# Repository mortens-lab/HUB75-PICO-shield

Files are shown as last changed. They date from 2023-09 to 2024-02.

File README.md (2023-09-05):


# HUB75-PICO-shield
HUB75 matrix display shield controlled by a Raspberry Pi Pico W

KiCad 7.0 files for shield

IMAGE ALT TEXT (http://www.youtube.com/watch?v=hoFy992Y98c "Video Title")

Link to youtube video : (https://youtu.be/hoFy992Y98c)

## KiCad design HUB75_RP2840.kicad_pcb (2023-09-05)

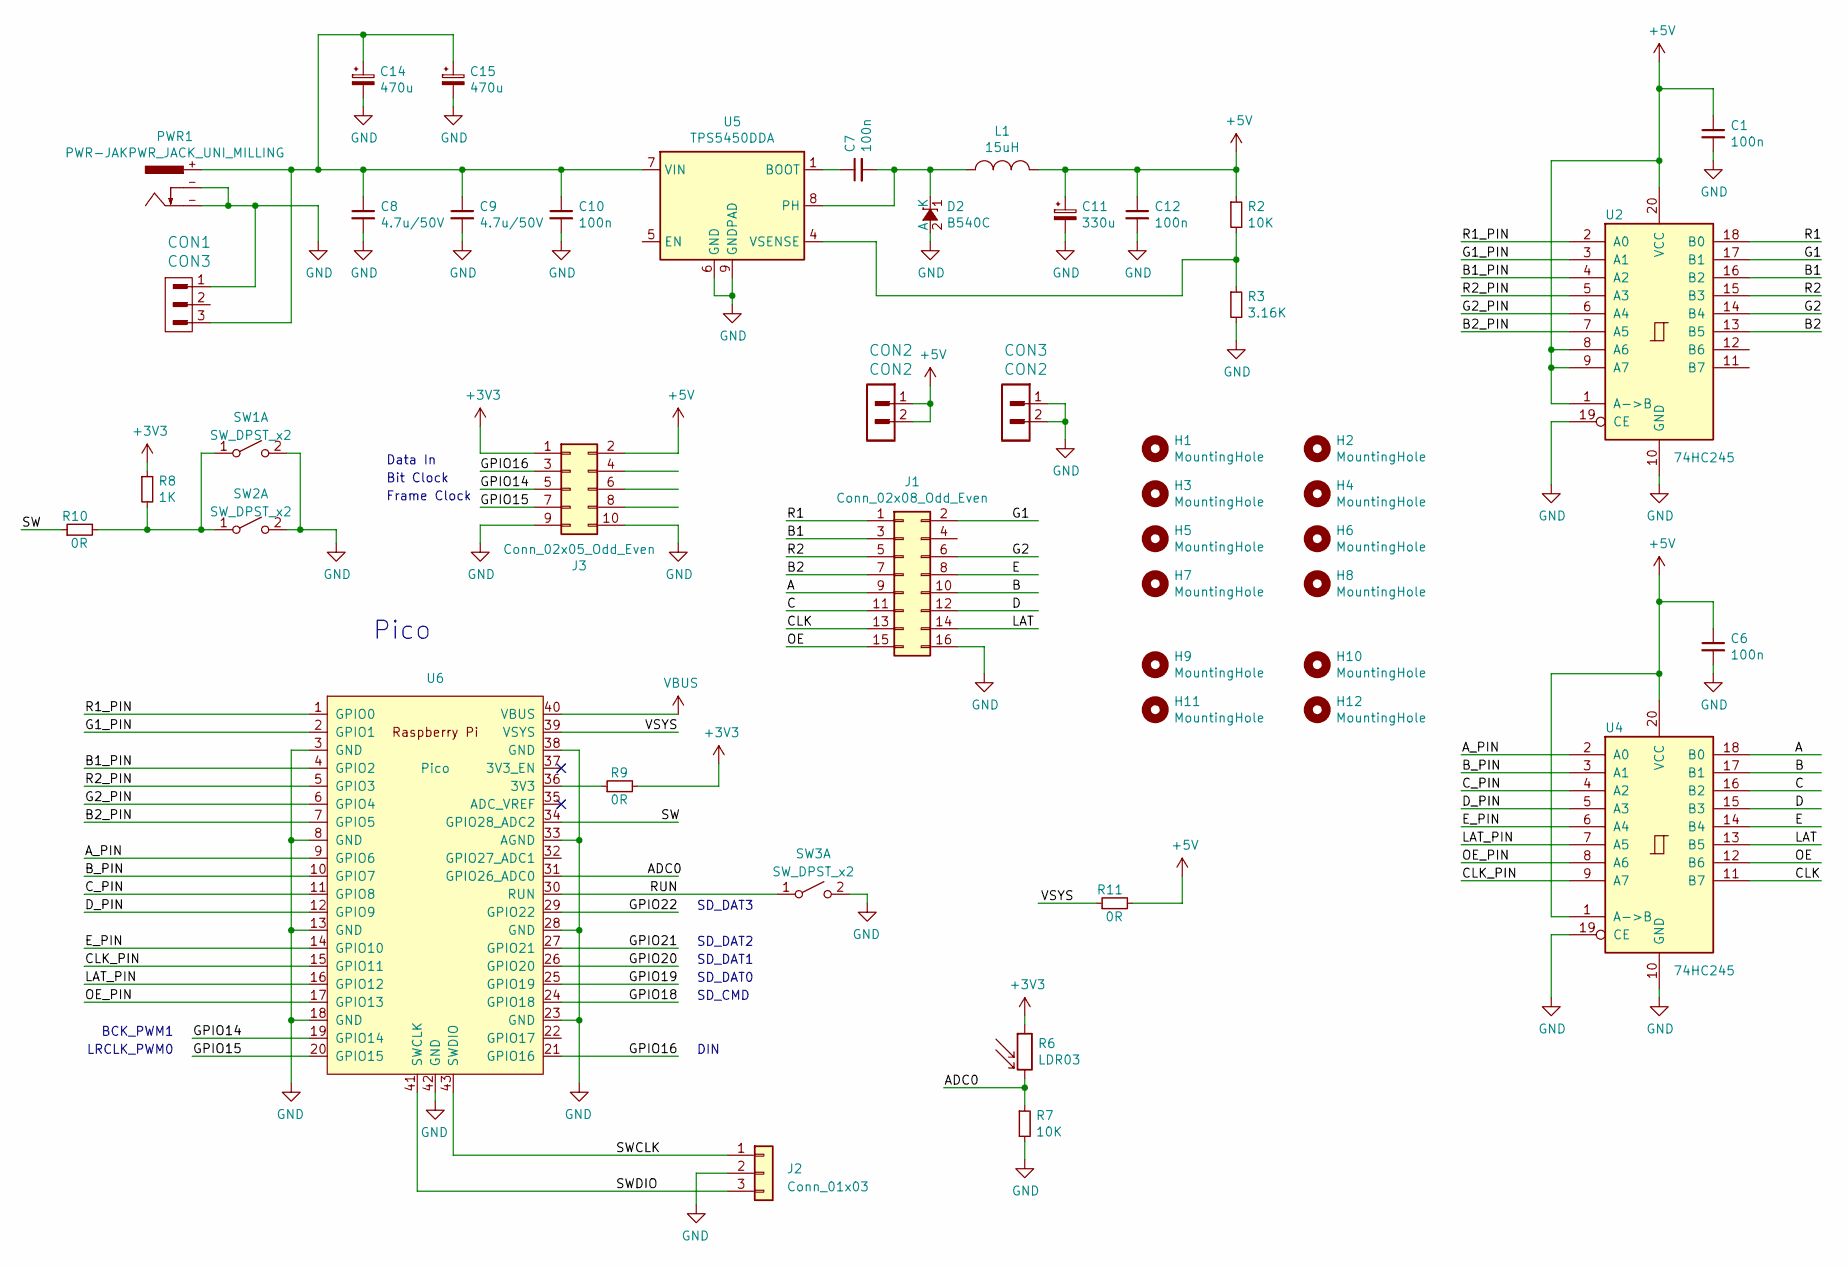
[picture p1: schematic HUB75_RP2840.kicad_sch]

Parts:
C1, C6, C7, C10, C12: 100n; C_0603_1608Metric
C8, C9: 4.7u/50V; C_1812_4532Metric
C11: 330u; CP_Elec_6.3x7.7
C14, C15: 470u; CP_Elec_8x10
CON1: CON3; TerminalBlock_Phoenix_MKDS-1,5-3-5.08_1x03_P5.08mm_Horizont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
CON2, CON3: CON2; TerminalBlock_Phoenix_MKDS-1,5-2-5.08_1x02_P5.08mm_Horizont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
D2: B540C; D_SMC
H1, H2, H3, H4, H5, H6, H7, H8: MountingHole; MountingHole_3.2mm_M3_Pad_Via
H9, H10, H11, H12: MountingHole; MountingHole_3.2mm_M3
J1: Conn_02x08_Odd_Even; IDC-Header_2x08_P2.54mm_Vertical
J2: Conn_01x03; PinHeader_1x03_P2.54mm_Vertical
J3: Conn_02x05_Odd_Even; PinHeader_2x05_P2.54mm_Vertical
L1: 15uH; L_12x12mm_H8mm
PWR1: PWR-JAKPWR_JACK_UNI_MILLING; PWRJ-2mm(YDJ-1136)
R2, R7: 10K; R_0603_1608Metric
R3: 3.16K; R_0603_1608Metric
R6: LDR03; R_LDR_10x8.5mm_P7.6mm_Vertical
R8: 1K; R_0603_1608Metric
R9, R10, R11: 0R; R_0603_1608Metric
SW1: SW_DPST_x2; SW_Tactile_SPST_Angled_PTS645Vx31-2LFS
SW2, SW3: SW_DPST_x2; SW_SPST_Omron_B3FS-100xP
U2, U4: 74HC245; SOIC-20W_7.5x12.8mm_P1.27mm
U5: TPS5450DDA; TI_SO-PowerPAD-8_ThermalVias
U6: Pico; RPi_Pico_WSMD_TH

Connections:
+3V3: J3.1, R6.1, R8.1, R9.2
+5V: C1.1, C6.1, C11.1, C12.1, CON2.1, CON2.2, J3.2, L1.2, R2.1, R11.2, U2.1 (A->B), U2.8 (A6), U2.9 (A7), U2.20 (VCC), U4.1 (A->B), U4.20 (VCC)
/A: J1.9, U4.18 (B0)
/ADC0: R6.2, R7.1, U6.31 (GPIO26_ADC0)
/A_PIN: U4.2 (A0), U6.9 (GPIO6)
/B: J1.10, U4.17 (B1)
/B1: J1.3, U2.16 (B2)
/B1_PIN: U2.4 (A2), U6.4 (GPIO2)
/B2: J1.7, U2.13 (B5)
/B2_PIN: U2.7 (A5), U6.7 (GPIO5)
/B_PIN: U4.3 (A1), U6.10 (GPIO7)
/C: J1.11, U4.16 (B2)
/CLK: J1.13, U4.11 (B7)
/CLK_PIN: U4.9 (A7), U6.15 (GPIO11)
/C_PIN: U4.4 (A2), U6.11 (GPIO8)
/D: J1.12, U4.15 (B3)
/D_PIN: U4.5 (A3), U6.12 (GPIO9)
/E: J1.8, U4.14 (B4)
/E_PIN: U4.6 (A4), U6.14 (GPIO10)
/G1: J1.2, U2.17 (B1)
/G1_PIN: U2.3 (A1), U6.2 (GPIO1)
/G2: J1.6, U2.14 (B4)
/G2_PIN: U2.6 (A4), U6.6 (GPIO4)
/GPIO14: J3.5, U6.19 (GPIO14)
/GPIO15: J3.7, U6.20 (GPIO15)
/GPIO16: J3.3, U6.21 (GPIO16)
/GPIO18: U6.24 (GPIO18)
/GPIO19: U6.25 (GPIO19)
/GPIO20: U6.26 (GPIO20)
/GPIO21: U6.27 (GPIO21)
/GPIO22: U6.29 (GPIO22)
/LAT: J1.14, U4.13 (B5)
/LAT_PIN: U4.7 (A5), U6.16 (GPIO12)
/OE: J1.15, U4.12 (B6)
/OE_PIN: U4.8 (A6), U6.17 (GPIO13)
/R1: J1.1, U2.18 (B0)
/R1_PIN: U2.2 (A0), U6.1 (GPIO0)
/R2: J1.5, U2.15 (B3)
/R2_PIN: U2.5 (A3), U6.5 (GPIO3)
/RUN: SW3.1 (A), U6.30 (RUN)
/SW: R10.1, U6.34 (GPIO28_ADC2)
/SWCLK: J2.1, U6.43 (SWDIO)
/SWDIO: J2.3, U6.41 (SWCLK)
/VSYS: R11.1, U6.39 (VSYS)
GND: C1.2, C6.2, C8.2, C9.2, C10.2, C11.2, C12.2, C14.2, C15.2, CON1.1, CON3.1, CON3.2, D2.2 (A), J1.16, J2.2, J3.9, J3.10, PWR1.-, R3.2, R7.2, SW1.2 (B), SW2.2 (B), SW3.2 (B), U2.10 (GND), U2.19 (CE), U4.10 (GND), U4.19 (CE), U5.6 (GND), U5.9 (GNDPAD), U6.3 (GND), U6.8 (GND), U6.13 (GND), U6.18 (GND), U6.23 (GND), U6.28 (GND), U6.33 (AGND), U6.38 (GND), U6.42 (GND)
unnamed: C7.2, D2.1 (K), L1.1, U5.8 (PH)
unnamed: R8.2, R10.2, SW1.1 (A), SW2.1 (A)
unnamed: C7.1, U5.1 (BOOT)
unnamed: C8.1, C9.1, C10.1, C14.1, C15.1, CON1.3, PWR1.+, U5.7 (VIN)
unnamed: R2.2, R3.1, U5.4 (VSENSE)
unnamed: R9.1, U6.36 (3V3)
VBUS: U6.40 (VBUS)

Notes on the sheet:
Pico
SD_DAT3
Bit Clock
SD_DAT2
SD_DAT0
SD_DAT1
Frame Clock
Data In
SD_CMD
LRCLK_PWM0
DIN
BCK_PWM1

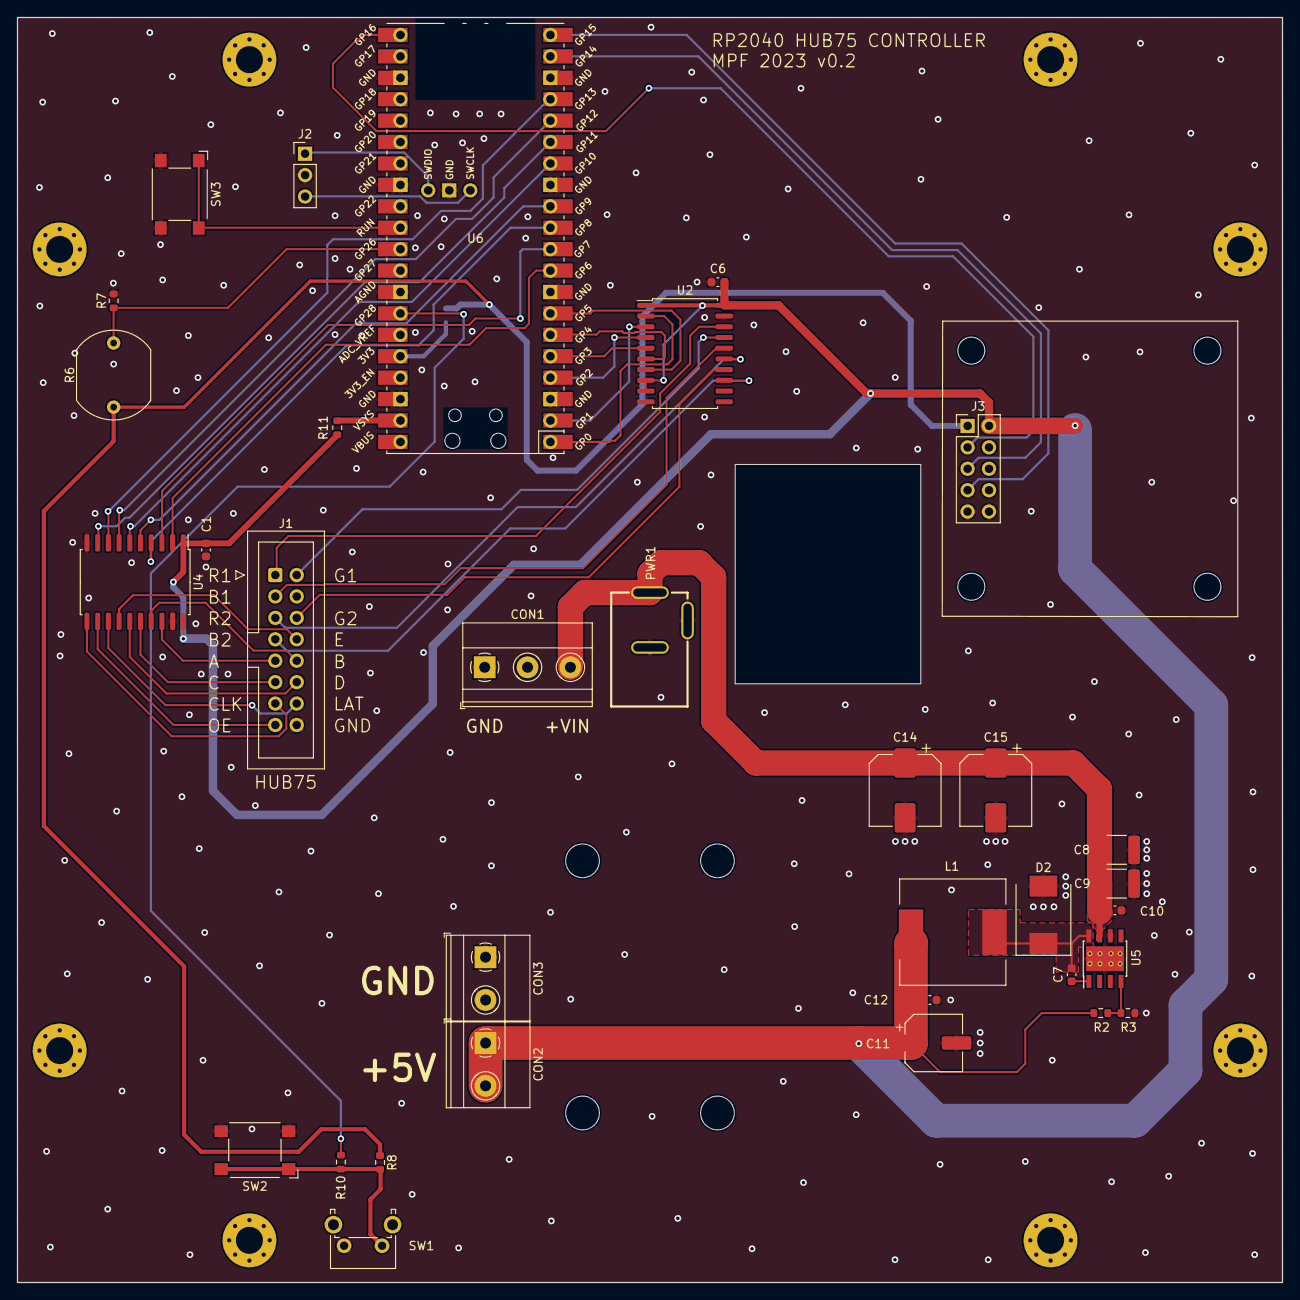
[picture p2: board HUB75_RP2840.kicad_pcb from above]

Board: 2 copper layers, 150.0 x 150.0 mm, 46 parts (1 on the bottom side), 46 nets.

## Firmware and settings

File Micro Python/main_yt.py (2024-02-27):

'''
raw_set_pixel.py
This example shows how to set the pixels on the display individually without having to use pico graphics.
This method can be used to save on memory usage.
'''

import time
import network
import uasyncio as asyncio
from machine import Pin
import machine
import WIFI_CONFIG
import hub75
from network_manager import NetworkManager
import ntptime
from micropython_youtube_api import YoutubeAPI
import json
import os
from machine import I2S




WIDTH = 64
HEIGHT = 64
p1 = 40

matrix = hub75.Hub75(WIDTH, HEIGHT, panel_type=hub75.PANEL_FM6126A)

# create the rtc object
rtc = machine.RTC()

matrix.start()
matrix.clear()
try:
    from secrets import WIFI_SSID, WIFI_PASSWORD
    wifi_available = True
except ImportError:
    print("Create secrets.py with your WiFi credentials to get time from NTP")
    wifi_available = False


# Hardware definitions
led = Pin("LED", Pin.OUT, value=1)

#HEIGHT = 64
#WIDTH = 64
#MAX_PIXELS = 64

#h75 = hub75.Hub75(WIDTH, HEIGHT, stb_invert=False)

#OK
def font_0(x_pos): 
    font_logic_line(x_pos,  0x0FFC)
    font_logic_line(x_pos+1,0x0FFC)
    font_logic_line(x_pos+2,0x3033)
    font_logic_line(x_pos+3,0x3033)
    font_logic_line(x_pos+4,0x30C3)
    font_logic_line(x_pos+5,0x30C3)
    font_logic_line(x_pos+6,0x3303)
    font_logic_line(x_pos+7,0x3303)
    font_logic_line(x_pos+8,0x0FFC)
    font_logic_line(x_pos+9,0x0FFC)
#OK
def font_1(x_pos): 
    font_logic_line(x_pos,  0x0000)
    font_logic_line(x_pos+1,0x0000)
    font_logic_line(x_pos+2,0x0C03)
    font_logic_line(x_pos+3,0x0C03)
    font_logic_line(x_pos+4,0x3FFF)
    font_logic_line(x_pos+5,0x3FFF)
    font_logic_line(x_pos+6,0x0003)
    font_logic_line(x_pos+7,0x0003)
    font_logic_line(x_pos+8,0x0000)
    font_logic_line(x_pos+9,0x0000)
#OK
def font_2(x_pos): 
    font_logic_line(x_pos,  0x0C3F)
    font_logic_line(x_pos+1,0x0C3F)
    font_logic_line(x_pos+2,0x30C3)
    font_logic_line(x_pos+3,0x30C3)
    font_logic_line(x_pos+4,0x30C3)
    font_logic_line(x_pos+5,0x30C3)
    font_logic_line(x_pos+6,0x30C3)
    font_logic_line(x_pos+7,0x30C3)
    font_logic_line(x_pos+8,0x0F03)
    font_logic_line(x_pos+9,0x0F03)
#OK
def font_3(x_pos): 
    font_logic_line(x_pos,  0x300C)
    font_logic_line(x_pos+1,0x300C)
    font_logic_line(x_pos+2,0x3003)
    font_logic_line(x_pos+3,0x3003)
    font_logic_line(x_pos+4,0x30C3)
    font_logic_line(x_pos+5,0x30C3)
    font_logic_line(x_pos+6,0x33C3)
    font_logic_line(x_pos+7,0x33C3)
    font_logic_line(x_pos+8,0x3C3C)
    font_logic_line(x_pos+9,0x3C3C)
#OK
def font_4(x_pos): 
    font_logic_line(x_pos,  0x00F0)
    font_logic_line(x_pos+1,0x00F0)
    font_logic_line(x_pos+2,0x0330)
    font_logic_line(x_pos+3,0x0330)
    font_logic_line(x_pos+4,0x0C30)
    font_logic_line(x_pos+5,0x0C30)
    font_logic_line(x_pos+6,0x3FFF)
    font_logic_line(x_pos+7,0x3FFF)
    font_logic_line(x_pos+8,0x0030)
    font_logic_line(x_pos+9,0x0030)
#OK
def font_5(x_pos): 
    font_logic_line(x_pos,  0x3F0C)
    font_logic_line(x_pos+1,0x3F0C)
    font_logic_line(x_pos+2,0x3303)
    font_logic_line(x_pos+3,0x3303)
    font_logic_line(x_pos+4,0x3303)
    font_logic_line(x_pos+5,0x3303)
    font_logic_line(x_pos+6,0x3303)
    font_logic_line(x_pos+7,0x3303)
    font_logic_line(x_pos+8,0x30FC)
    font_logic_line(x_pos+9,0x30FC)
#OK
def font_6(x_pos): 
    font_logic_line(x_pos,  0x03FC)
    font_logic_line(x_pos+1,0x03FC)
    font_logic_line(x_pos+2,0x0CC3)
    font_logic_line(x_pos+3,0x0CC3)
    font_logic_line(x_pos+4,0x30C3)
    font_logic_line(x_pos+5,0x30C3)
    font_logic_line(x_pos+6,0x30C3)
    font_logic_line(x_pos+7,0x30C3)
    font_logic_line(x_pos+8,0x303C)
    font_logic_line(x_pos+9,0x303C)
#OK
def font_7(x_pos): 
    font_logic_line(x_pos,  0x3003)
    font_logic_line(x_pos+1,0x3003)
    font_logic_line(x_pos+2,0x300C)
    font_logic_line(x_pos+3,0x300C)
    font_logic_line(x_pos+4,0x3030)
    font_logic_line(x_pos+5,0x3030)
    font_logic_line(x_pos+6,0x30C0)
    font_logic_line(x_pos+7,0x30C0)
    font_logic_line(x_pos+8,0x3F00)
    font_logic_line(x_pos+9,0x3F00)
#OK   
def font_8(x_pos):
    font_logic_line(x_pos,  0x0F3C)
    font_logic_line(x_pos+1,0x0F3C)
    font_logic_line(x_pos+2,0x30C3)
    font_logic_line(x_pos+3,0x30C3)
    font_logic_line(x_pos+4,0x30C3)
    font_logic_line(x_pos+5,0x30C3)
    font_logic_line(x_pos+6,0x30C3)
    font_logic_line(x_pos+7,0x30C3)
    font_logic_line(x_pos+8,0x0F3C)
    font_logic_line(x_pos+9,0x0F3C)
#OK
def font_9(x_pos): 
    font_logic_line(x_pos,  0x0F03)
    font_logic_line(x_pos+1,0x0F03)
    font_logic_line(x_pos+2,0x30C3)
    font_logic_line(x_pos+3,0x30C3)
    font_logic_line(x_pos+4,0x30C3)
    font_logic_line(x_pos+5,0x30C3)
    font_logic_line(x_pos+6,0x30CC)
    font_logic_line(x_pos+7,0x30CC)
    font_logic_line(x_pos+8,0x0FF0)
    font_logic_line(x_pos+9,0x0FF0)

z=0

def font_logic_line(x,value):
    for y in range(0, 14):
        if value>>y & 1:
            matrix.set_pixel(x, 50-y, 90, 90, 90)
            
        else:
            matrix.set_pixel(x, 50-y, 0, 0, 0)
            



def box(x1,y1,x2,y2,color): 
    for x in range(x1, x2):
        for y in range(y1, y2):
          # bitmap[x, y] = color
            if color == 1:
                matrix.set_pixel(x, y, 90, 90, 90)
                
            if color == 2:
                matrix.set_pixel(x, y, 90, 0, 0)
                

def logic_line(x,value):
    for y in range(0, 8):
        if value>>y & 1:
            matrix.set_pixel(x, 61-y, 90, 90, 90)
            
        else:
            matrix.set_pixel(x, 61-y, 0, 0, 0)
            

# Draw even more pixels
box(19,3,45,4,2)
box(15,4,49,5,2)
box(13,5,51,6,2)
box(12,6,52,7,2)
box(11,7,53,11,2)
box(10,11,54,26,2)
box(11,26,53,30,2)
box(12,30,52,31,2)
box(13,31,51,32,2)
box(15,32,49,33,2)
box(19,33,45,34,2)

box(27,12,29,25,1)
box(29,13,31,24,1)
box(31,14,33,23,1)
box(33,15,35,22,1)
box(35,16,37,21,1)
matrix.set_pixel(37,17,100,100,100)
matrix.set_pixel(37,18,100,100,100)
matrix.set_pixel(37,19,100,100,100)
matrix.set_pixel(38,18,100,100,100)
#m
logic_line(2,0x3F) 
logic_line(3,0x20)
logic_line(4,0x38)
logic_line(5,0x20)
logic_line(6,0x1F)
#a
logic_line(8,0x16) 
logic_line(9,0x29)
logic_line(10,0x29)
logic_line(11,0x1F)
#d
logic_line(13,0x1e) 
logic_line(14,0x21)
logic_line(15,0x21)
logic_line(16,0xFF)
#e
logic_line(18,0x1e) 
logic_line(19,0x29)
logic_line(20,0x29)
logic_line(21,0x18)

#b
logic_line(24,0xFF) 
logic_line(25,0x21)
logic_line(26,0x21)
logic_line(27,0x1F)
#y
logic_line(29,0x38) 
logic_line(30,0x04)
logic_line(31,0x04)
logic_line(32,0x3F)
matrix.set_pixel(30,62,100,100,100)
matrix.set_pixel(31,62,100,100,100)

#m
logic_line(35,0x3F) 
logic_line(36,0x20)
logic_line(37,0x38)
logic_line(38,0x20)
logic_line(39,0x1F)
#o
logic_line(41,0x1e) 
logic_line(42,0x21)
logic_line(43,0x21)
logic_line(44,0x1e)
#o
logic_line(46,0x3F) 
logic_line(47,0x10)
logic_line(48,0x20)
#t
logic_line(49,0x20)
logic_line(50,0xFE)
logic_line(51,0x21)
#e
logic_line(53,0x1e) 
logic_line(54,0x29)
logic_line(55,0x29)
logic_line(56,0x18)
#n
logic_line(58,0x3F) 
logic_line(59,0x20)
logic_line(60,0x20)
logic_line(61,0x1F)


#font_1(0)
#font_0(9)
#font_0(20)
#font_0(31)
#font_0(42)
#font_0(53)

#font_5(3)
#font_6(15)
#font_7(27)
#font_8(39)
#font_9(51)

#time.sleep(5)
num = 100000
count = 0
sub_counter=3613
oldnum=100000

while num != 0:
    num //= 10
    count += 1

#print("Number of digits: " + str(count))

#x, y = rand_pixel()
#r, g, b = rand_color()
#   print('Setting Pixel x: {0} y: {1}'.format(x, y))
#
#



def get_digit(number, n):
  #  print("digits: " + str(number // 10**n % 10))
    return number // 10**n % 10

def show_digit(num,p):
    if get_digit(num, p) == 0:
        font_0(xpos)
    if get_digit(num, p) == 1:
        font_1(xpos)
    if get_digit(num, p) == 2:
        font_2(xpos)
    if get_digit(num, p) == 3:
        font_3(xpos)
    if get_digit(num, p) == 4:
        font_4(xpos)
    if get_digit(num, p) == 5:
        font_5(xpos)
    if get_digit(num, p) == 6:
        font_6(xpos)
    if get_digit(num, p) == 7:
        font_7(xpos)
    if get_digit(num, p) == 8:
        font_8(xpos)
    if get_digit(num, p) == 9:
        font_9(xpos)
print("starter1")
time.sleep(1)




def play_owlsound():
    matrix.stop()
    if os.uname().machine.count("PYBv1"):

    # ======= I2S CONFIGURATION =======
        SCK_PIN = "Y6"
        WS_PIN = "Y5"
        SD_PIN = "Y8"
        I2S_ID = 2
        BUFFER_LENGTH_IN_BYTES = 5000
    # ======= I2S CONFIGURATION =======
  
    elif os.uname().machine.count("Raspberry"):

        # ======= I2S CONFIGURATION =======
        SCK_PIN = 14
        WS_PIN = 15
        SD_PIN = 16
        I2S_ID = 0
        BUFFER_LENGTH_IN_BYTES = 5000
        # ======= I2S CONFIGURATION =======

    else:
        print("Warning: program not tested with this board")

    # ======= AUDIO CONFIGURATION =======
    #AV_FILE = "Oh No.wav"
    WAV_FILE = "free-sound-1674745346.wav"
    WAV_SAMPLE_SIZE_IN_BITS = 16
    FORMAT = I2S.STEREO
    SAMPLE_RATE_IN_HZ = 32000
    # ======= AUDIO CONFIGURATION =======

    audio_out = I2S(
        I2S_ID,
        sck=Pin(SCK_PIN),
        ws=Pin(WS_PIN),
        sd=Pin(SD_PIN),
        mode=I2S.TX,
        bits=WAV_SAMPLE_SIZE_IN_BITS,
        format=FORMAT,
        rate=SAMPLE_RATE_IN_HZ,
        ibuf=BUFFER_LENGTH_IN_BYTES,
    )

    wav = open(WAV_FILE, "rb")
    pos = wav.seek(244)  # advance to first byte of Data section in WAV file

    # allocate sample array
    # memoryview used to reduce heap allocation
    wav_samples = bytearray(1000)
    wav_samples_mv = memoryview(wav_samples)
    time.sleep(3)

    # continuously read audio samples from the WAV file
    # and write them to an I2S DAC
    print("==========  START PLAYBACK ==========")
    try:
        while True:
            num_read = wav.readinto(wav_samples_mv)
            # end of WAV file?
            if num_read == 0:
                # end-of-file, advance to first byte of Data section
                #_ = wav.seek(44)
                break
            else:
                _ = audio_out.write(wav_samples_mv[:num_read])

    except (KeyboardInterrupt, Exception) as e:
        print("caught exception {} {}".format(type(e).__name__, e))

    # cleanup
    wav.close()
    audio_out.deinit()
    print("Done")
    matrix.start()
    
def sync_time():
    if not wifi_available:
        return

    # Start connection
    wlan = network.WLAN(network.STA_IF)
    wlan.active(True)
    wlan.config(pm=0xa11140)  # Turn WiFi power saving off for some slow APs
    wlan.connect(WIFI_SSID, WIFI_PASSWORD)

    # Wait for connect success or failure
    max_wait = 100
    while max_wait > 0:
        if wlan.status() < 0 or wlan.status() >= 3:
            break
        max_wait -= 1
        print('waiting for connection...')
        time.sleep(0.2)

       # redraw_display_if_reqd()

    if max_wait > 0:
        print("Connected")

        try:
            ntptime.settime()
            print("Time set")
        except OSError:
            pass

   # wlan.disconnect()
   # wlan.active(False)

# NTP synchronizes the time to UTC, this allows you to adjust the displayed time
analog_value = machine.ADC(26)

utc_offset = 0

cnt = 0;

year, month, day, wd, hour, minute, second, _ = rtc.datetime()

last_second = second

sync_time()
# time.sleep(5)

##############################################################

# Read config
with open('config.json') as f:
    config = json.load(f)

# Create an instance of the YoutubeApi

with YoutubeAPI( config["channelid"], config["appkeyid"], config["query_interval_sec"] ) as data:
  # Read the data every X seconds
    update_interval = 61
    update_stats_time = time.time() - 10

    while True:

        if update_stats_time < time.time():
            update_stats_time = time.time() + update_interval

            print ("Subs {}".format( data.subs ) )
            print ("Views {}".format( data.views ) )
            print ("Videos {}".format( data.videos ) )

            num =  int(data.subs)
            if num>oldnum:
                print ("ny sub")
                play_owlsound()
            if num==oldnum:
                print ("ingen ny sub")
            cnt=cnt+1
            print("counter = ")
            year, month, day, wd, hour, minute, second, _ = rtc.datetime()
            print(cnt)
            print(year)
            print(month)
            print(day)
            print(wd)
            print(hour)
            print(minute)
            print(second)
            
            count = 0

            while num != 0:
                num //= 10
                count += 1
               # print("Number of digits: " + str(count))
            
            num=int(data.subs)
        
            oldnum=num
        
            box(1,37,63,51,0)
        
            if count == 1:
                xpos=27
                show_digit(num,0)
            if count == 2:
                xpos=21
                show_digit(num,1)
                xpos=33
                show_digit(num,0)
            if count == 3:
                xpos=15
                show_digit(num,2)
                xpos=27
                show_digit(num,1)
                xpos=39
                show_digit(num,0)
            if count == 4:
                xpos=9
                show_digit(num,3)
                xpos=21
                show_digit(num,2)
                xpos=33
                show_digit(num,1)  
                xpos=45
                show_digit(num,0)
            if count == 5:
                xpos=3
                show_digit(num,4)
                xpos=15
                show_digit(num,3)
                xpos=27
                show_digit(num,2)
                xpos=39
                show_digit(num,1)  
                xpos=51
                show_digit(num,0)
            if count == 6:
                xpos=-1
                show_digit(num,5)
                xpos=9
                show_digit(num,4)
                xpos=20
                show_digit(num,3)
                xpos=31
                show_digit(num,2)
                xpos=42
                show_digit(num,1)  
                xpos=53
                show_digit(num,0)
        
        matrix.set_pixel(0,63,0,100,0)
         
        time.sleep(0.2)
        matrix.set_pixel(0,63,0,0,0)
         
        time.sleep(0.2)

        potentiometer = analog_value.read_u16() >> 4
      #  print(potentiometer.read_u16())
        conversion_factor = 3.3/(4096)
      #  print("{:.2f}".format(potentiometer * conversion_factor)) 
 
        if (potentiometer * conversion_factor) > 0.3:
            p1=50
        else:
            p1=0

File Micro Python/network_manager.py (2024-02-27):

import rp2
import network
import machine
import uasyncio


class NetworkManager:
    _ifname = ("Client", "Access Point")

    def __init__(self, country="GB", client_timeout=60, access_point_timeout=5, status_handler=None, error_handler=None):
        rp2.country(country)
        self._ap_if = network.WLAN(network.AP_IF)
        self._sta_if = network.WLAN(network.STA_IF)

        self._mode = network.STA_IF
        self._client_timeout = client_timeout
        self._access_point_timeout = access_point_timeout
        self._status_handler = status_handler
        self._error_handler = error_handler
        self.UID = ("{:02X}" * 8).format(*machine.unique_id())

    def isconnected(self):
        return self._sta_if.isconnected() or self._ap_if.isconnected()

    def config(self, var):
        if self._sta_if.active():
            return self._sta_if.config(var)
        else:
            if var == "password":
                return self.UID
            return self._ap_if.config(var)

    def mode(self):
        if self._sta_if.isconnected():
            return self._ifname[0]
        if self._ap_if.isconnected():
            return self._ifname[1]
        return None

    def ifaddress(self):
        if self._sta_if.isconnected():
            return self._sta_if.ifconfig()[0]
        if self._ap_if.isconnected():
            return self._ap_if.ifconfig()[0]
        return '0.0.0.0'

    def disconnect(self):
        if self._sta_if.isconnected():
            self._sta_if.disconnect()
        if self._ap_if.isconnected():
            self._ap_if.disconnect()

    async def wait(self, mode):
        while not self.isconnected():
            self._handle_status(mode, None)
            await uasyncio.sleep_ms(1000)

    def _handle_status(self, mode, status):
        if callable(self._status_handler):
            self._status_handler(self._ifname[mode], status, self.ifaddress())

    def _handle_error(self, mode, msg):
        if callable(self._error_handler):
            if self._error_handler(self._ifname[mode], msg):
                return
        raise RuntimeError(msg)

    async def client(self, ssid, psk):
        if self._sta_if.isconnected():
            self._handle_status(network.STA_IF, True)
            return

        self._ap_if.disconnect()
        self._ap_if.active(False)

        self._sta_if.active(True)
        self._sta_if.config(pm=0xa11140)
        self._sta_if.connect(ssid, psk)

        try:
            await uasyncio.wait_for(self.wait(network.STA_IF), self._client_timeout)
            self._handle_status(network.STA_IF, True)

        except uasyncio.TimeoutError:
            self._sta_if.active(False)
            self._handle_status(network.STA_IF, False)
            self._handle_error(network.STA_IF, "WIFI Client Failed")

    async def access_point(self):
        if self._ap_if.isconnected():
            self._handle_status(network.AP_IF, True)
            return

        self._sta_if.disconnect()
        self._sta_if.active(False)

        self._ap_if.ifconfig(("10.10.1.1", "255.255.255.0", "10.10.1.1", "10.10.1.1"))
        self._ap_if.config(password=self.UID)
        self._ap_if.active(True)

        try:
            await uasyncio.wait_for(self.wait(network.AP_IF), self._access_point_timeout)
            self._handle_status(network.AP_IF, True)

        except uasyncio.TimeoutError:
            self._sta_if.active(False)
            self._handle_status(network.AP_IF, False)
            self._handle_error(network.AP_IF, "WIFI Client Failed")
